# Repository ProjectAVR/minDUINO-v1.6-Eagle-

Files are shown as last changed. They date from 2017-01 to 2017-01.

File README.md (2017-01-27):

# minDUINO-v1.6-Eagle-
A small footprint Arduino Clone, originally designed as an educationl tool.

[Edited text from Projectavr.com]
If you look online you will find a myriad of Arduino™ clones of all different shapes and sizes. So why would I want to produce yet more? I was inspired to create the minDUINO boards because my friend's daughter, I will call her Amelia, had found an interest in electronics. Amelia’s father and I had given her several things to build, commercially available kits, but I wanted to encourage her to experiment. Since I have a familiarity with AVRs and Arduino™, I elected to follow that path.

The minDUINO is designed to be easy to assemble, so it is a two layer through-hole design, and has no SMD components. It has headers for FTDI, ICSP and GPIO breakouts.

The original designs were carried out with EagleCAD.

This repository holds the Eagle files and the final Gerbers which can all be used to create physical boards.

The minDUINO designs are licenced under Creative Commons Attribution-ShareAlike 4.0 International License.

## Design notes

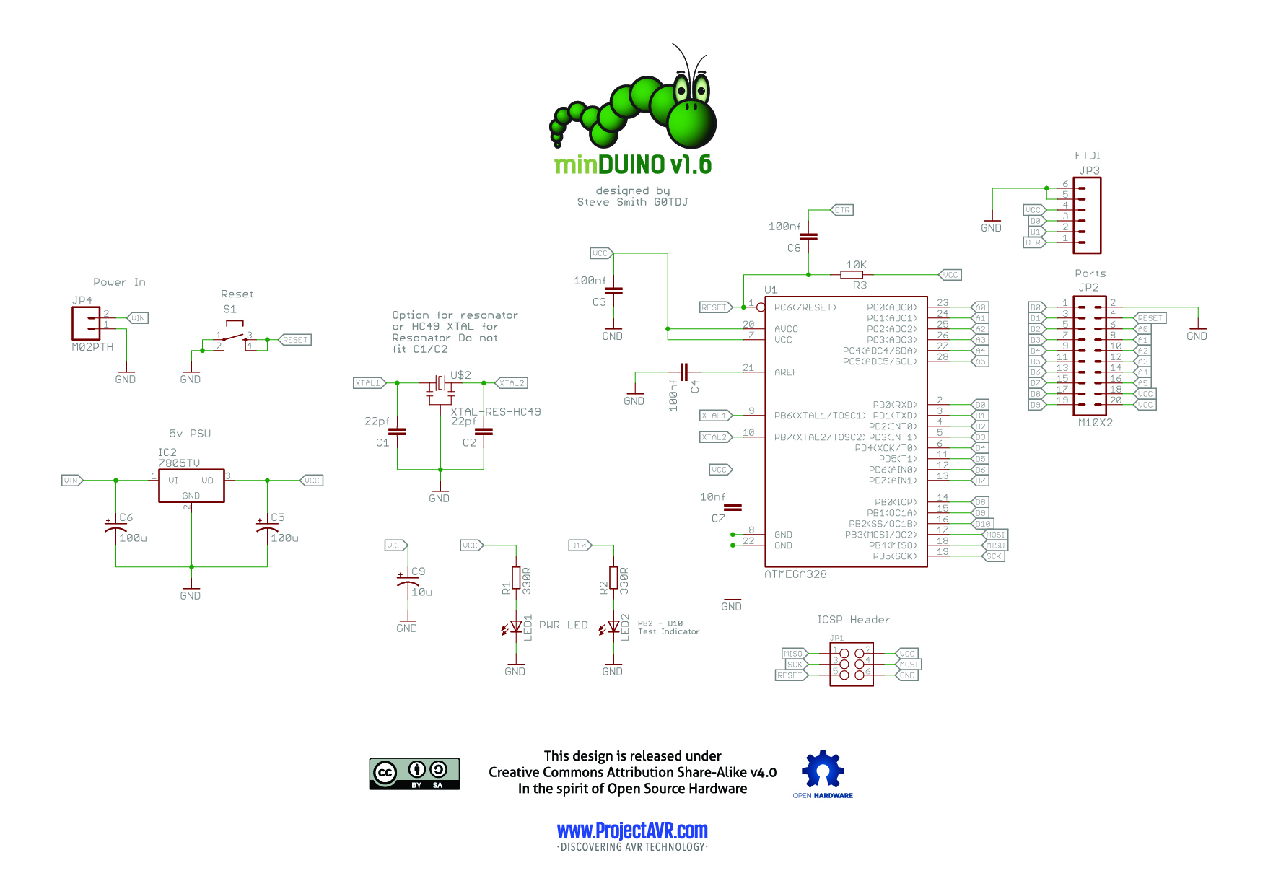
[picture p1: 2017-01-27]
minDUINO v1.6 Schematic.jpg

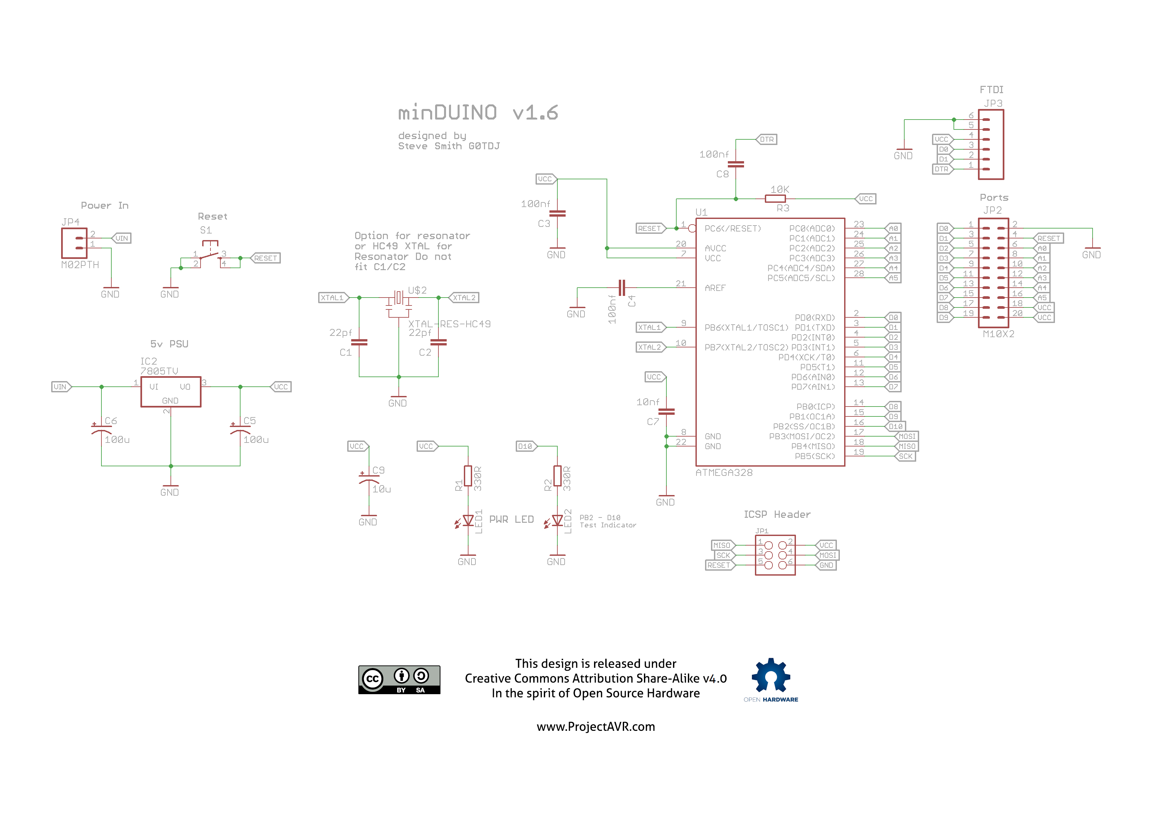
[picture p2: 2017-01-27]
minDUINO v1.6_Schematic.jpg

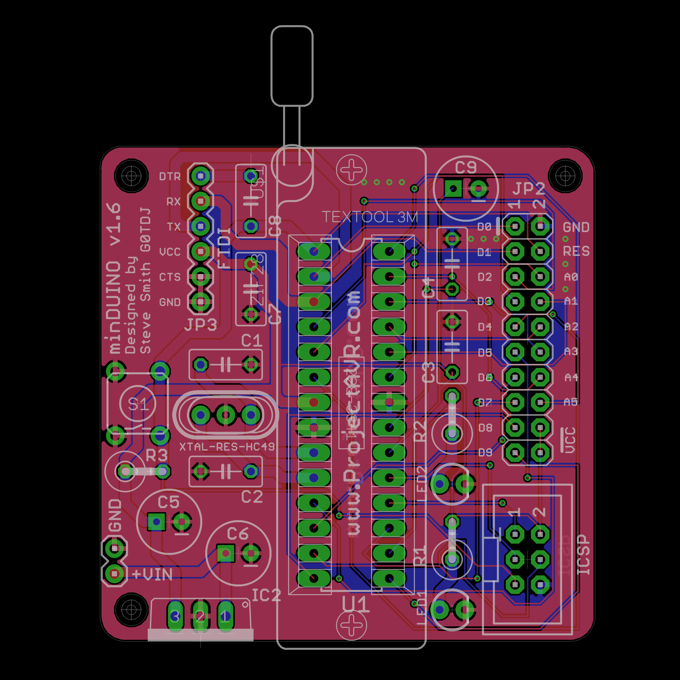
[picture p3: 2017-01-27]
minDUINO v1.6-ZIF.png

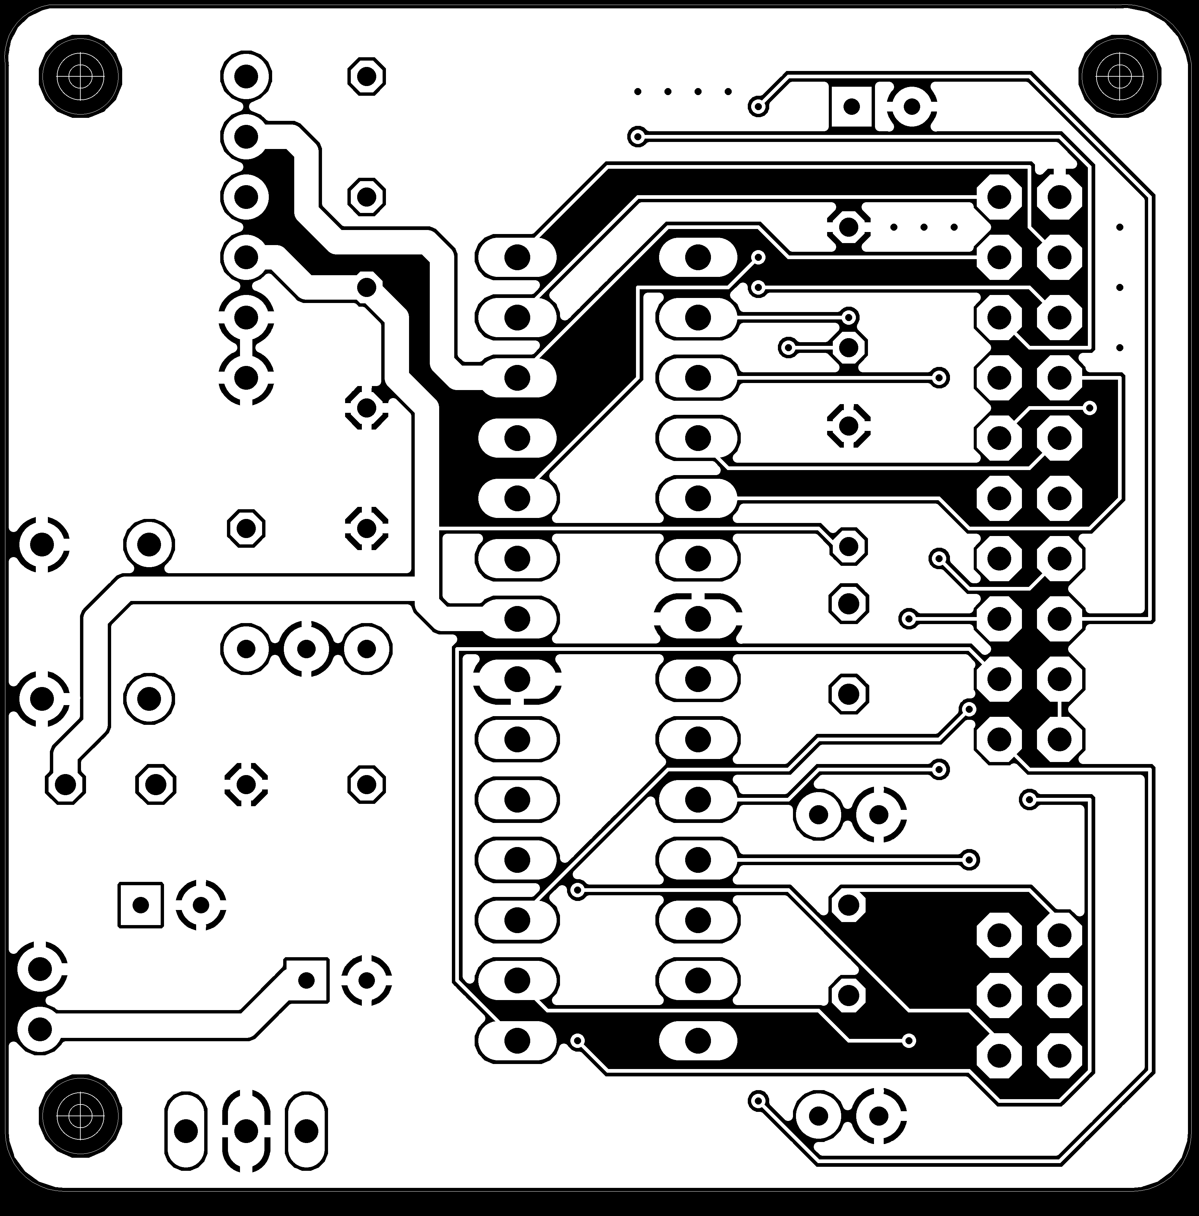
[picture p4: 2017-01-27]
MinDuino v1.6 Top Copper.png

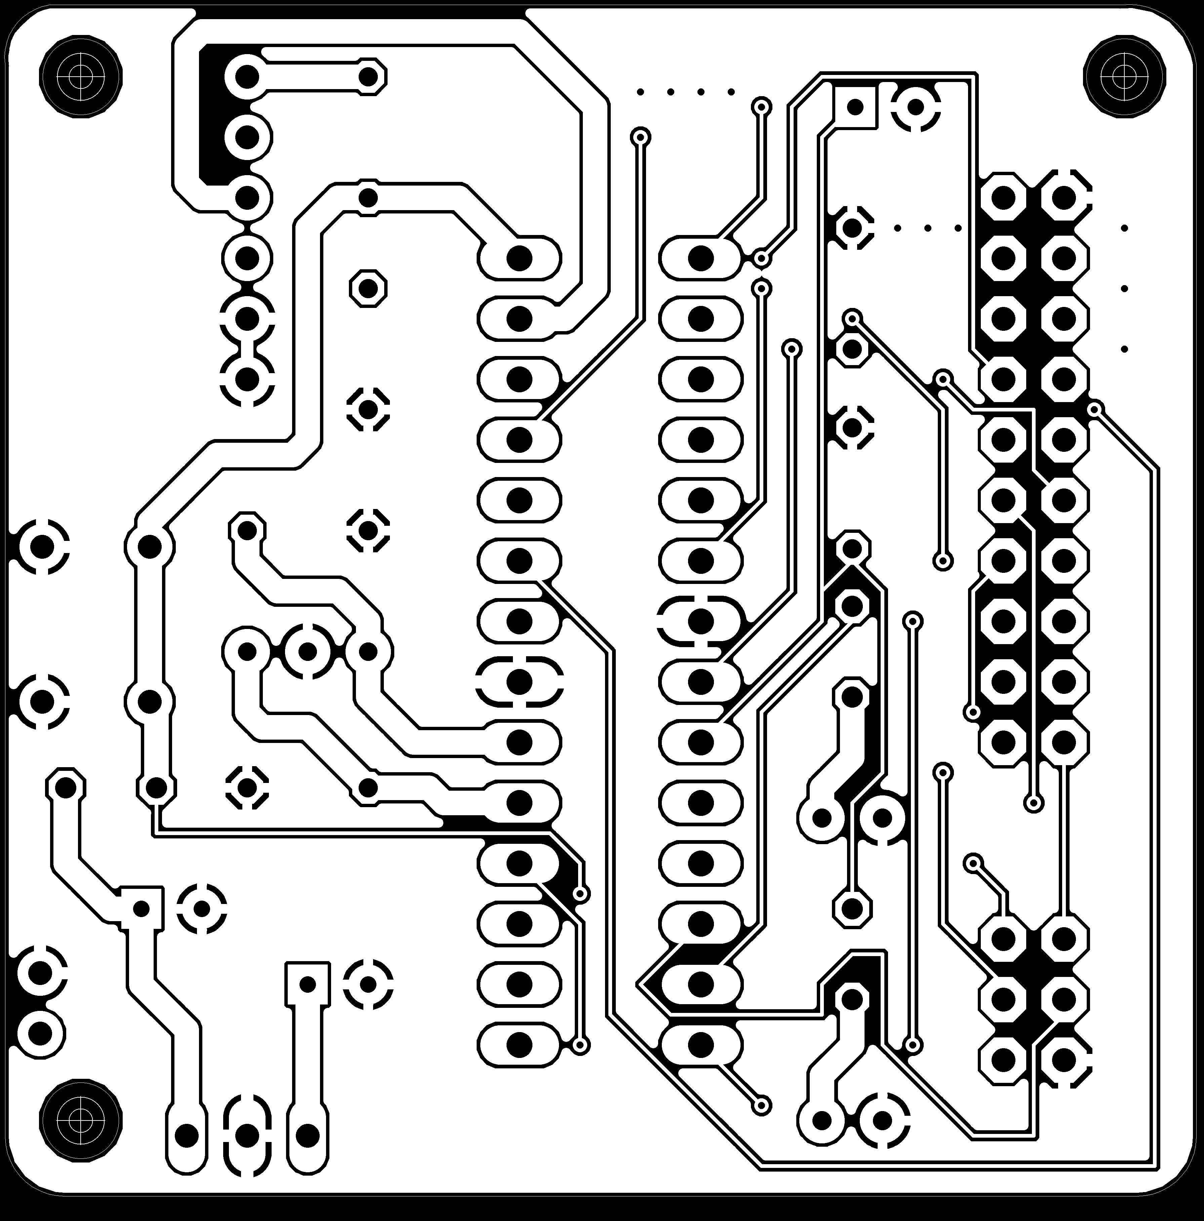
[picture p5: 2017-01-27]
MinDuino v1.6 Bottom Copper.png

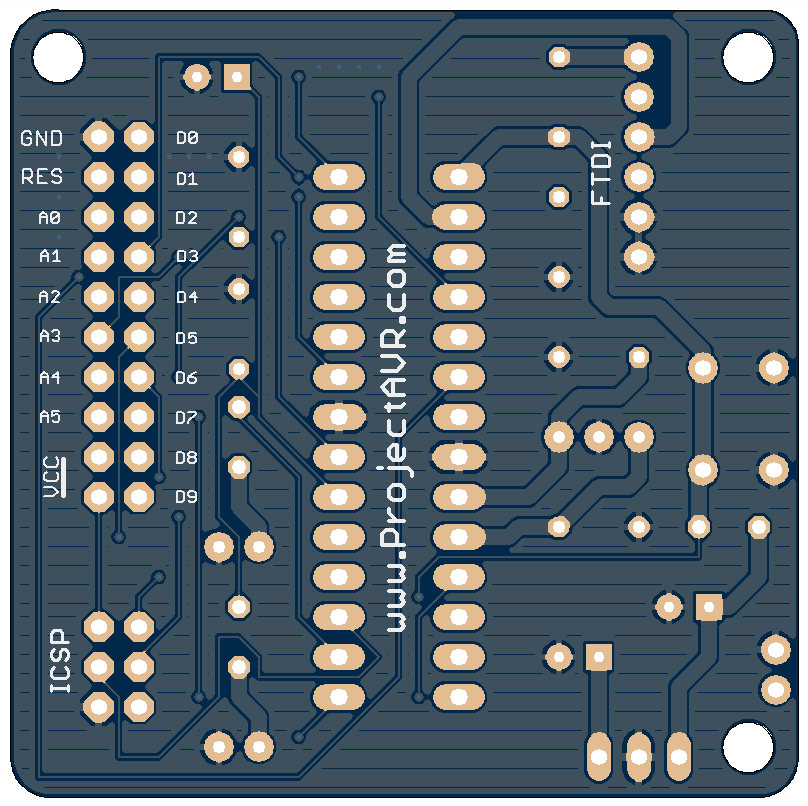
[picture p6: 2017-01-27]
minDUINO v1.6_Gerblook_BACK.jpg

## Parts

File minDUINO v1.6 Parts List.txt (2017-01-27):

minDUINO v1.6 Parts List

Assembly variant: 

Part     Value          

C1       22pf
C2       22pf
C3       100nf
C4       100nf
C5       100uf
C6       100uf
C7       10nf
C8       100nf
C9       10uf
IC2      7805 5V  linear Regulator
JP1      Molex Type 2X03 Shrouded Header
JP2      Molex Type 10X02 Header
JP3      Molex Type 1X06 Header
JP4      Molex Type 1x02 Header
LED1   LED3MM  Red
LED2   LED3MM  Green
R1       330R
R2       330R
R3       10K
S1        Tactile Momentary Push Switch
U$2      Low profile HC49 crystal or Resonator (If a resonator is used, do not fit C1/2)
U1       ATMEGA328P

1x 28-Pin 3M/Textool ZIF Socket: 228-3341 (Optional)

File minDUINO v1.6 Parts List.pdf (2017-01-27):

Part | Value | Notes
C1 | 22pf
C2 | 22pf
C3 | 100nf
C4 | 100nf
C5 | 100uf
C6 | 100uf
C7 | 10nf
C8 | 100nf
C9 | 10uf
IC2 | 7805 5V linear Regulator
JP1 | Molex Type 2X03 Shrouded Header
JP2 | Molex Type 10X02 Header
JP3 | Molex Type 1X06 Header
JP4 | Molex Type 1x02 Header
LED1 | LED3MM Red | Or colour to suit
LED2 | LED3MM Green | Or colour to suit
R1 | 330R
R2 | 330R
R3 | 10K
S1 | Tactile Momentary Push Switch
U$2 | Low profile HC49 crystal or Resonator (If a resonator is used) | If resonator used, do not fit C1/2
U1 | ATMEGA328P
| 1x 28-Pin 3M/Textool ZIF Socket: 228-3341 (Optional)

## Partlist - MinDuino v1.6

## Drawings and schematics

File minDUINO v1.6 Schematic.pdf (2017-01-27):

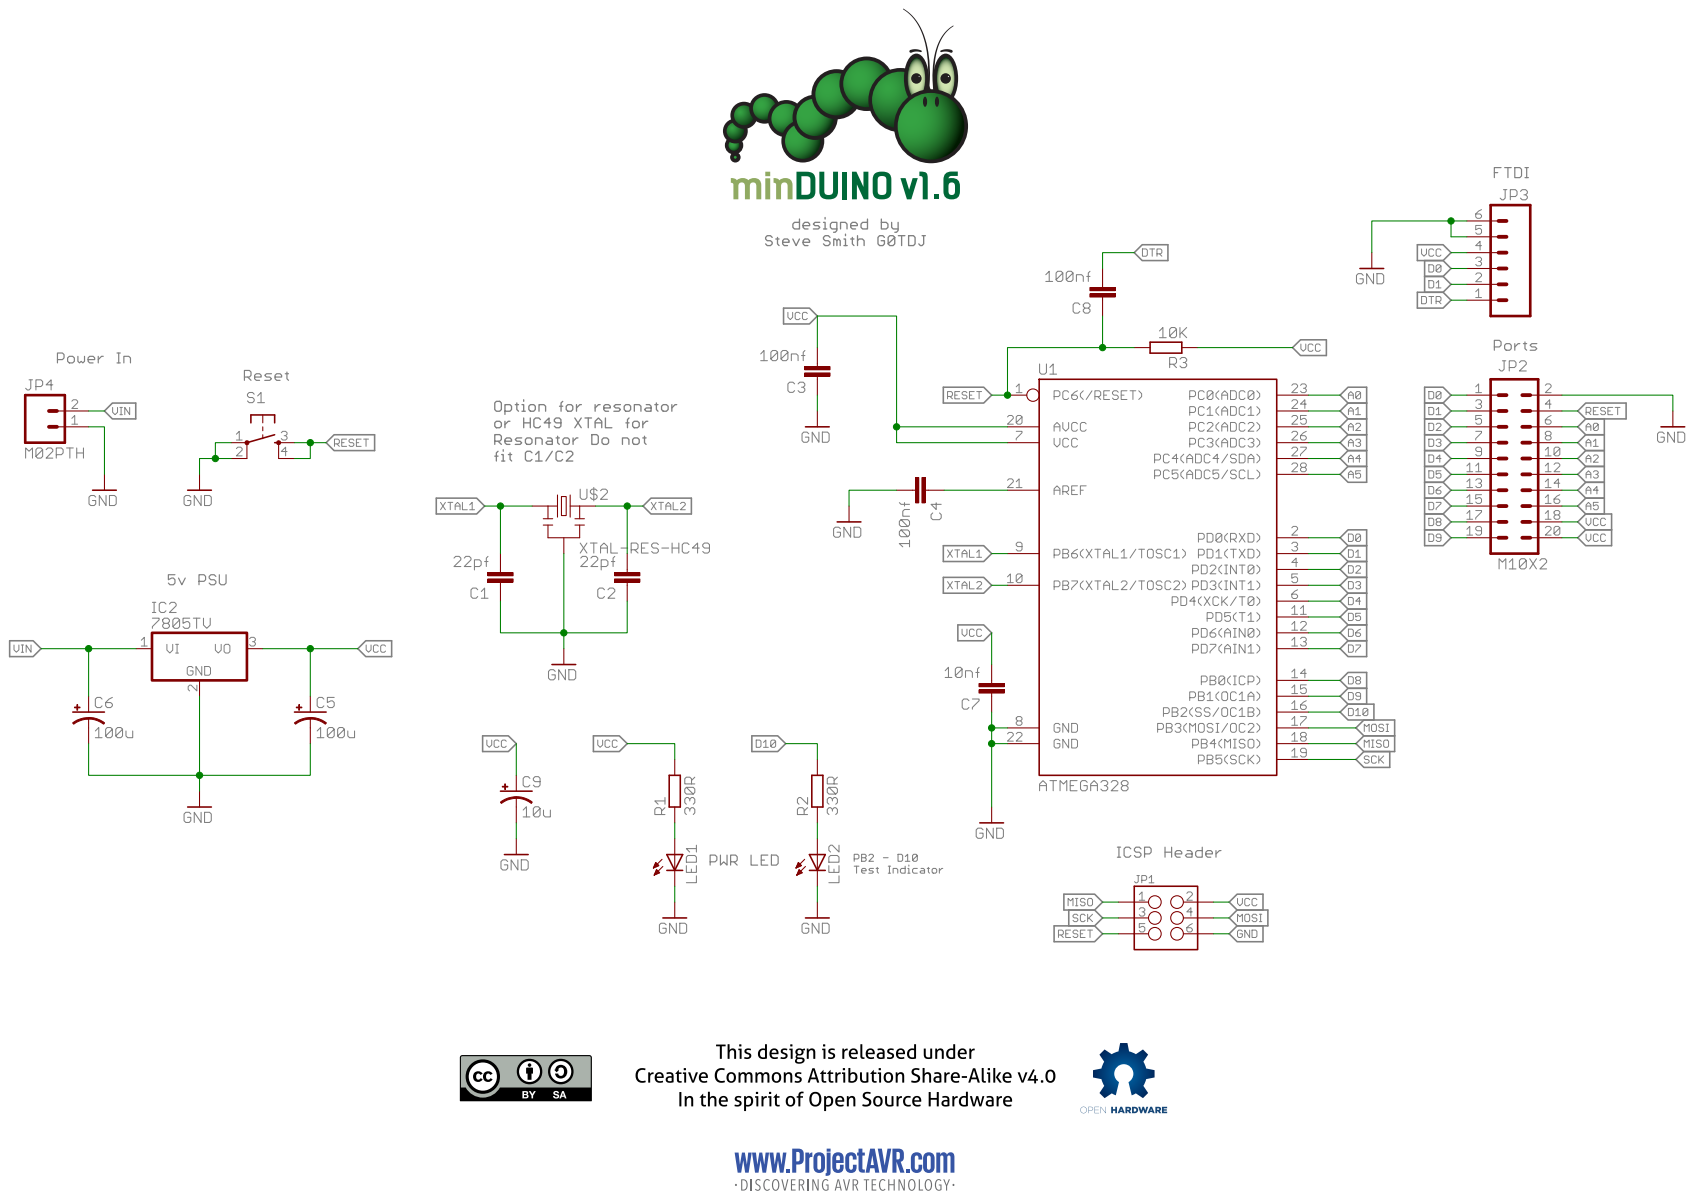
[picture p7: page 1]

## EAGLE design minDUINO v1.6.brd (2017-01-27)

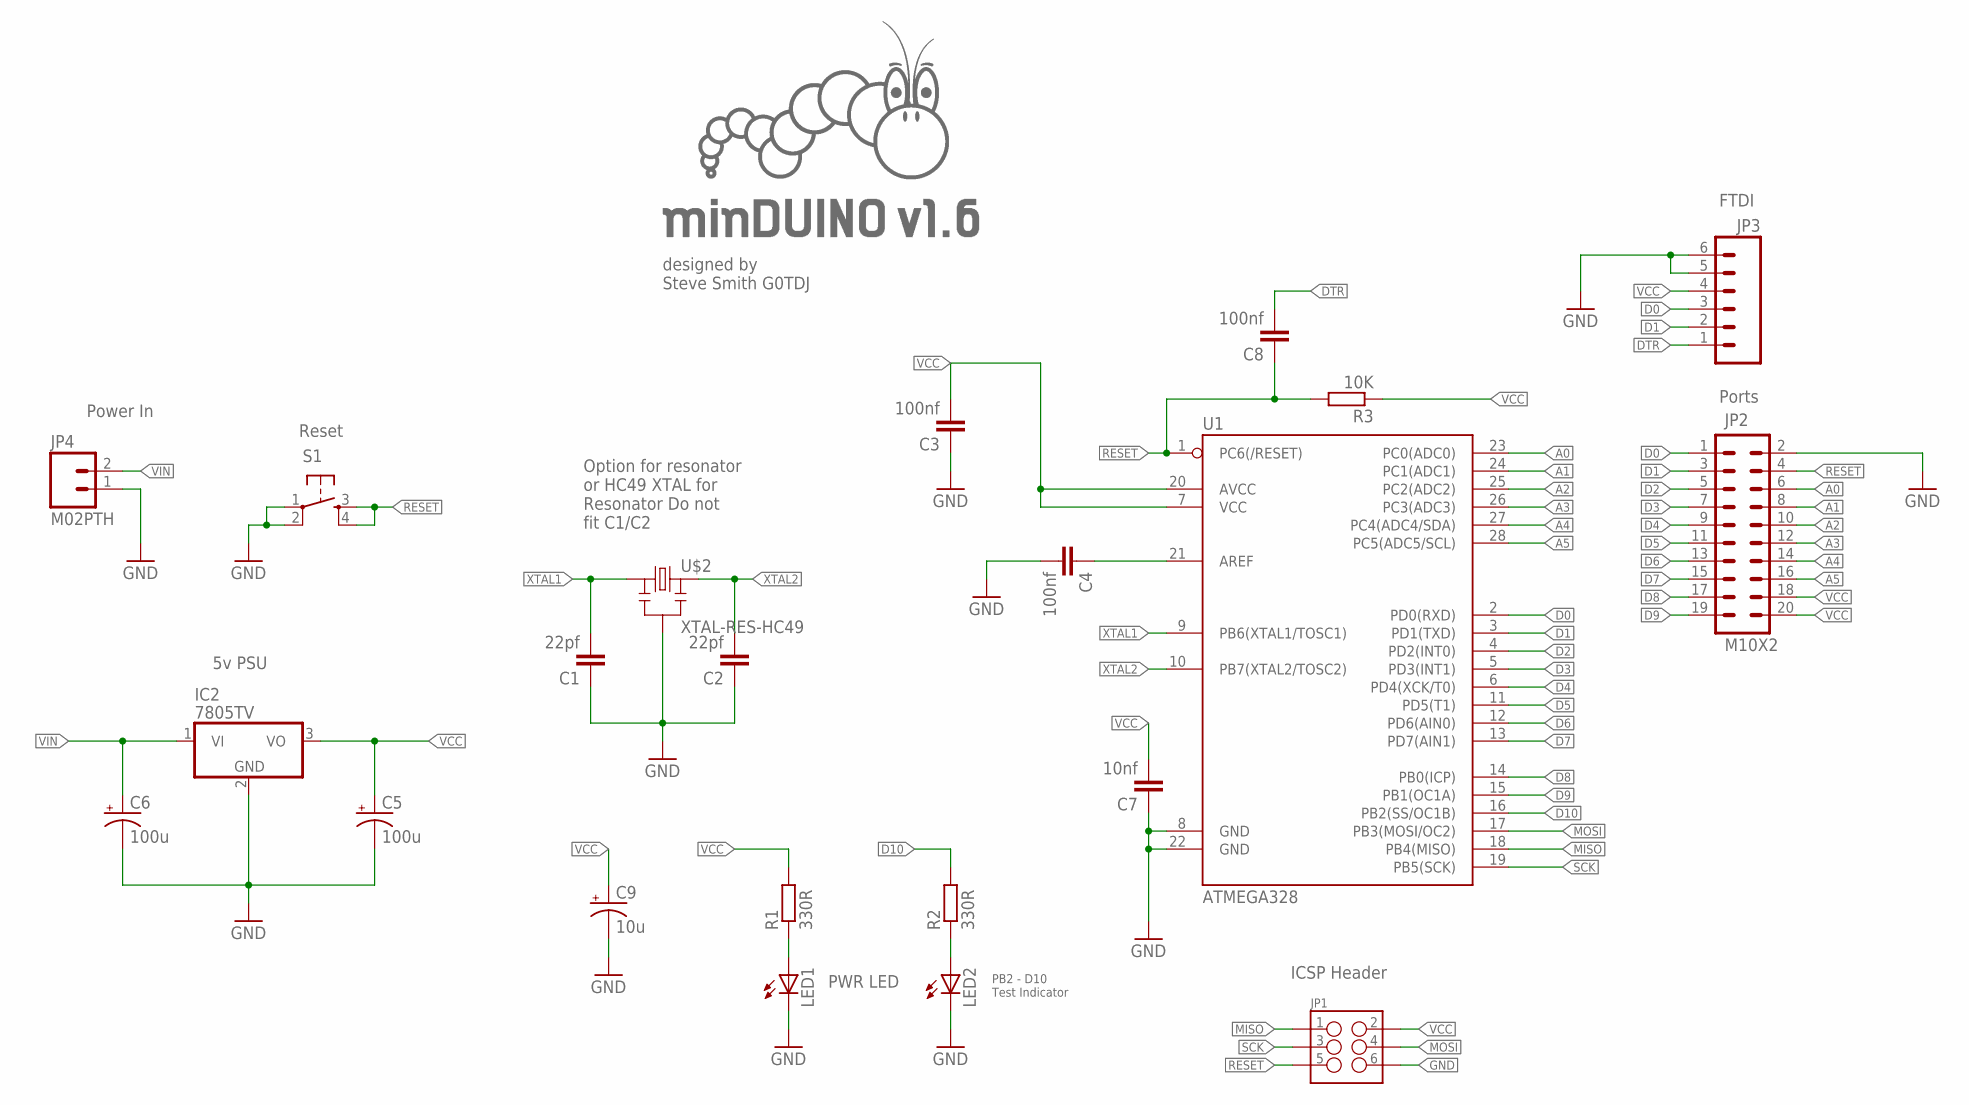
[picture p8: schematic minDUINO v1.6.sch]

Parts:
C1, C2: 22pf; C050-030X075
C3, C4, C8: 100nf; C050-030X075
C5, C6: 100u; CPOL-RADIAL-100UF-25V
C7: 10nf; C050-030X075
C9: 10u; CPOL-RADIAL-100UF-25V
IC2: 7805TV; TO220V
JP1: M03X2SHROUD; 2X3-SHROUDED
JP2: M10X2; 2X10
JP3: M06SIP; 1X06
JP4: M02PTH; 1X02
LED1, LED2: LED3MM
R1, R2: 330R; 0411V
R3: 10K; 0411V
S1: TAC_SWITCHPTH; TACTILE-PTH
U1: ATMEGA328; DIL28-3
U$1: MINDUINO_WORDMARK_V1.6
U$2: XTAL-RES-HC49
U$4: MINDUINO_CATERPILLAR

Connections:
A0: JP2.6, U1.23 (PC0(ADC0))
A1: JP2.8, U1.24 (PC1(ADC1))
A2: JP2.10, U1.25 (PC2(ADC2))
A3: JP2.12, U1.26 (PC3(ADC3))
A4: JP2.14, U1.27 (PC4(ADC4/SDA))
A5: JP2.16, U1.28 (PC5(ADC5/SCL))
D0: JP2.1, JP3.3, U1.2 (PD0(RXD))
D1: JP2.3, JP3.2, U1.3 (PD1(TXD))
D2: JP2.5, U1.4 (PD2(INT0))
D3: JP2.7, U1.5 (PD3(INT1))
D4: JP2.9, U1.6 (PD4(XCK/T0))
D5: JP2.11, U1.11 (PD5(T1))
D6: JP2.13, U1.12 (PD6(AIN0))
D7: JP2.15, U1.13 (PD7(AIN1))
D8: JP2.17, U1.14 (PB0(ICP))
D9: JP2.19, U1.15 (PB1(OC1A))
D10: R2.2, U1.16 (PB2(SS/OC1B))
DTR: C8.2, JP3.1
GND: C1.1, C2.1, C3.1, C4.2, C5.2 (-), C6.2 (-), C7.1, C9.2 (-), IC2.2 (GND), JP1.6, JP2.2, JP3.5, JP3.6, JP4.1, LED1.K (C), LED2.K (C), S1.1, S1.2, U1.8 (GND), U1.22 (GND), U$2.2
MISO: JP1.1, U1.18 (PB4(MISO))
MOSI: JP1.4, U1.17 (PB3(MOSI/OC2))
unnamed: LED2.A, R2.1
unnamed: C4.1, U1.21 (AREF)
unnamed: LED1.A, R1.1
RESET: C8.1, JP1.5, JP2.4, R3.2, S1.3, S1.4, U1.1 (PC6(/RESET))
SCK: JP1.3, U1.19 (PB5(SCK))
VCC: C3.2, C5.1 (+), C7.2, C9.1 (+), IC2.3 (VO), JP1.2, JP2.18, JP2.20, JP3.4, R1.2, R3.1, U1.7 (VCC), U1.20 (AVCC)
VIN: C6.1 (+), IC2.1 (VI), JP4.2
XTAL1: C1.2, U1.9 (PB6(XTAL1/TOSC1)), U$2.1
XTAL2: C2.2, U1.10 (PB7(XTAL2/TOSC2)), U$2.3

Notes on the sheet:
PB2 - D10 Test Indicator
designed by Steve Smith G0TDJ
5v PSU
Reset
Power In
ICSP Header
PWR LED
FTDI
Ports
Option for resonator or HC49 XTAL for Resonator Do not fit C1/C2

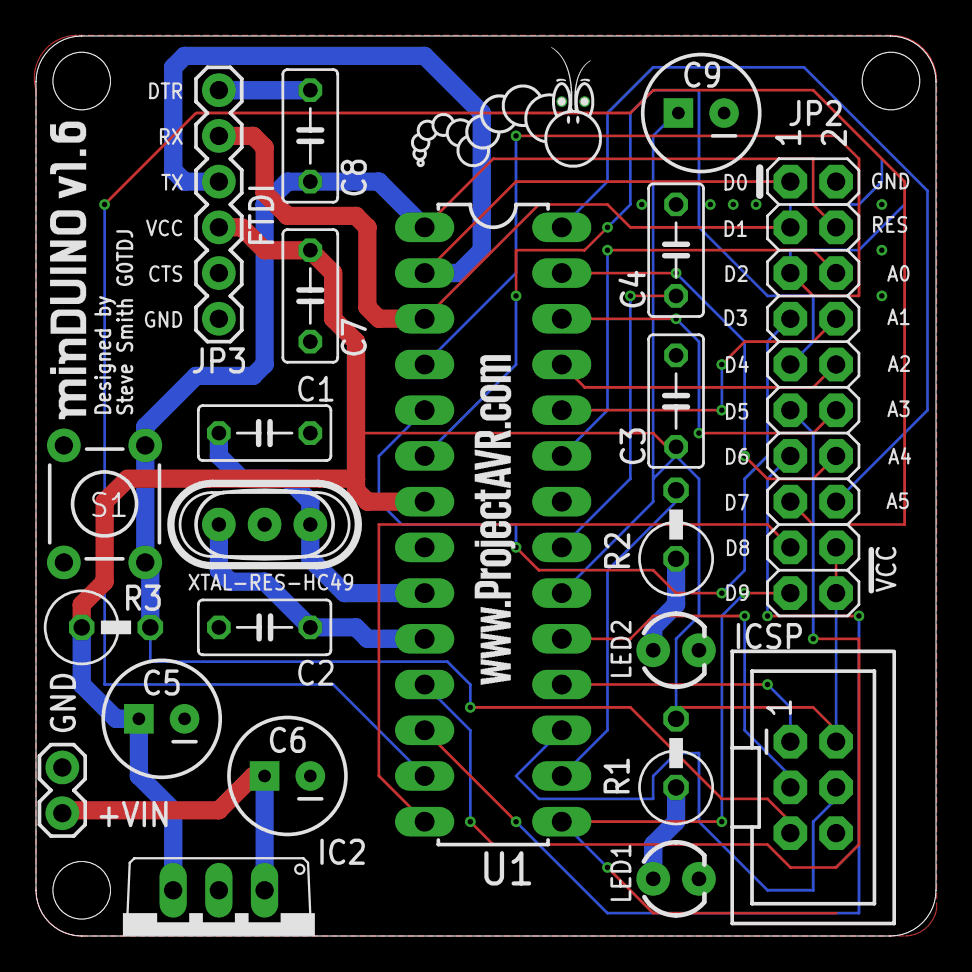
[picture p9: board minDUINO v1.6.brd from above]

Board: 2 copper layers, 50.0 x 50.0 mm, 26 parts (1 on the bottom side), 30 nets.

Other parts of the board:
U$3, U$5: PROJECTAVR_LOGO_1

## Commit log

2017-01-27 Update README.md
    Added description of the minDUINO boards.
2017-01-27 Added Gerbers
    [minDUINO v1.6_board_outline.gm1, minDUINO v1.6_bottom_copper.gbl, minDUINO v1.6_bottom_paste.gbp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]
2017-01-27 Added Eagle files, schematic and parts list
    [minDUINO v1.6.brd, minDUINO v1.6.sch]

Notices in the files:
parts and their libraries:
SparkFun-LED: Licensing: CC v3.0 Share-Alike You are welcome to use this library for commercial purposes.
